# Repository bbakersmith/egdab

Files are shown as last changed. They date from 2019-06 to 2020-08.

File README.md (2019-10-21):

# Egdab

An orchid shaped conference badge built around an ATTiny1606, created for
DefCon 27. Features audio, temperature, and touch sensors, as well as numerous
buttons, dipswitches, and potentiometers for user input. Outputs in the form of
several RGB LEDs and a two digit seven segment display.

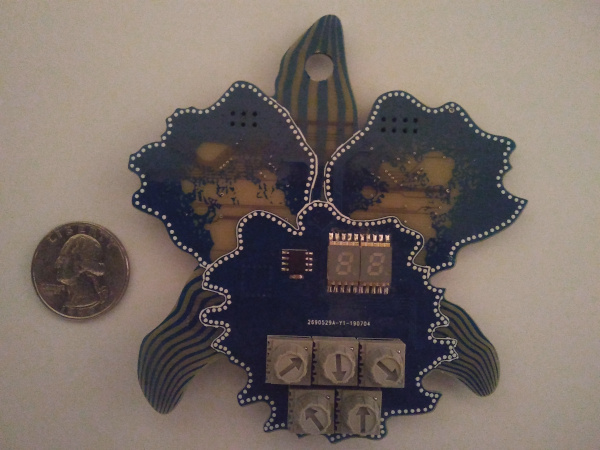
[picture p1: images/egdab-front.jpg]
Egdab front
\
Front

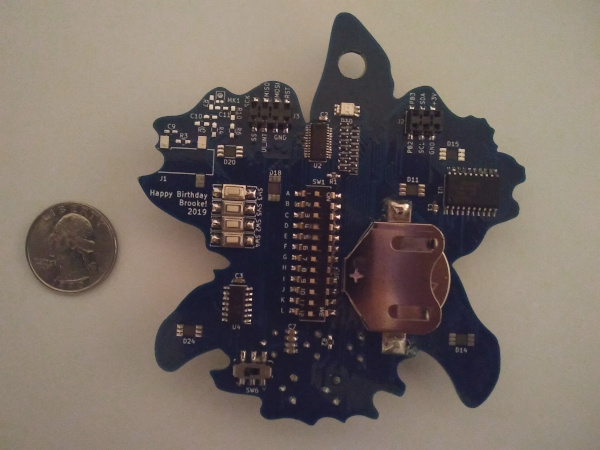
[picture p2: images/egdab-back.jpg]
Egdab back
\
Back

# License

Copyright Ben Baker-Smith 2019.

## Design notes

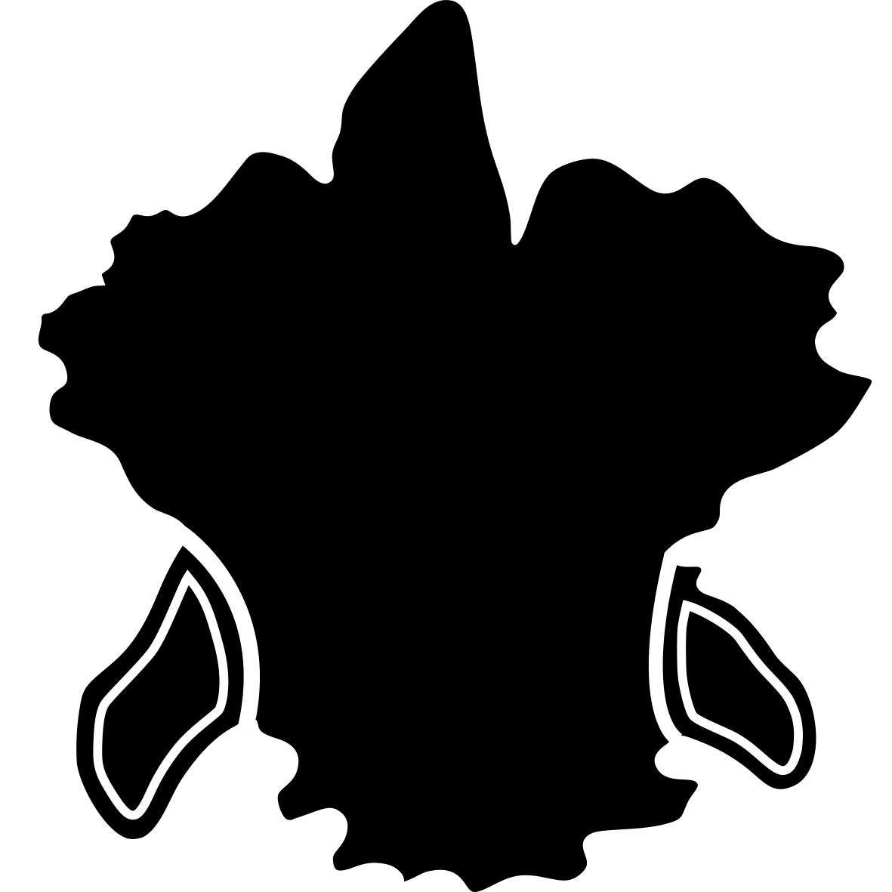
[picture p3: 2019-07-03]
graphic/exports/ground-1.png

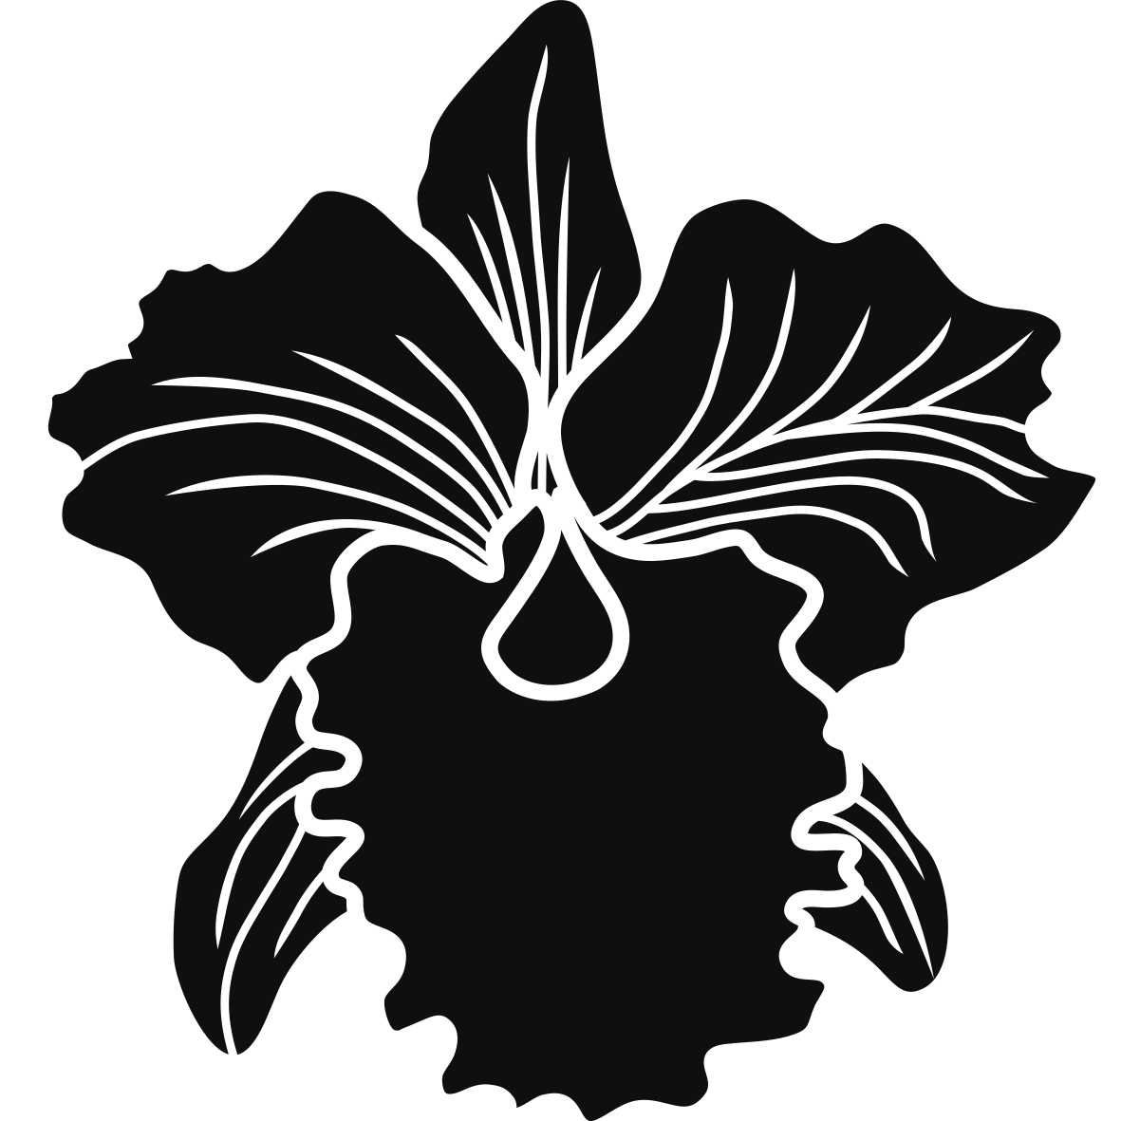
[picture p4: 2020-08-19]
kicad/graphics/orchid.png

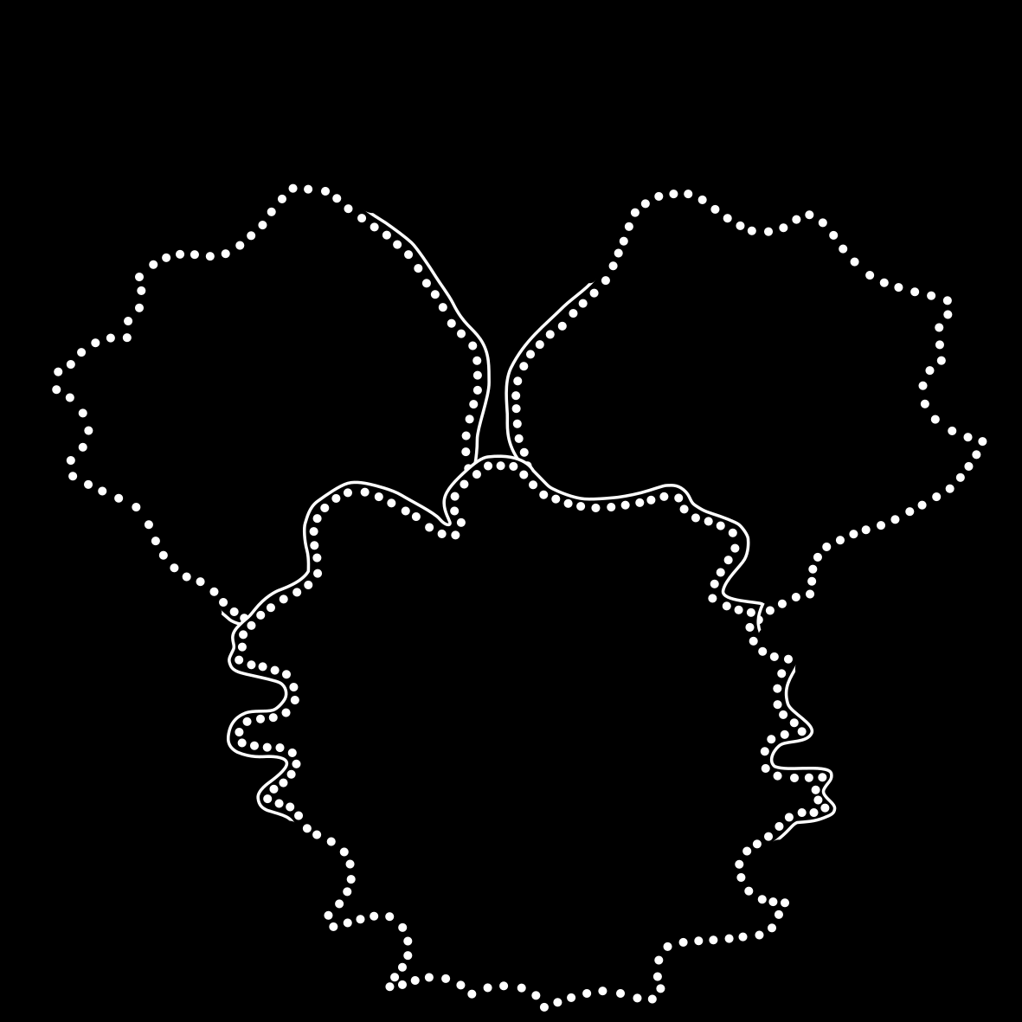
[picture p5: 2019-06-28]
graphic/exports/silkscreen-1.png

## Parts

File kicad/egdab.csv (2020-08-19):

Source: | /home/ben/dev/egdab/kicad/egdab.sch
Date: | Mon 17 Aug 2020 06:51:07 PM EDT
Tool: | Eeschema 5.1.5-1.fc30
Component Count: | 51
Ref | Value | Footprint | Datasheet | Manufacturer | Vendor
BT1 | CR2450VP | Battery_Holders:Keystone_3008_1x2450-CoinCell | ~
C1 | 22uF | Capacitors_SMD:C_0603_HandSoldering | ~
C2 | 22uF | Capacitors_SMD:C_0603_HandSoldering | ~
C3 | 22uF | Capacitors_SMD:C_0603_HandSoldering | ~
C4 | 22uF | Capacitors_SMD:C_0603_HandSoldering | ~
C5 | 22uF | Capacitors_SMD:C_0603_HandSoldering | ~
C6 | 22uF | Capacitors_SMD:C_0603_HandSoldering | ~
C9 | 10uF | Capacitors_SMD:C_0603_HandSoldering | ~
C10 | 10uF | Capacitors_SMD:C_0603_HandSoldering | ~
D1 | LED_RGB | BBS Components:LED_RGB_SMD_PLCC4_Reverse_XZMDKCBDDG45S | ~
D2 | LED_RGB | BBS Components:LED_RGB_SMD_PLCC4_Reverse_XZMDKCBDDG45S | ~
D3 | LED_RGB | BBS Components:LED_RGB_SMD_PLCC4_Reverse_XZMDKCBDDG45S | ~
D4 | LED_RGB | BBS Components:LED_RGB_SMD_PLCC4_Reverse_XZMDKCBDDG45S | ~
D5 | LED_RGB | BBS Components:LED_RGB_SMD_PLCC4_Reverse_XZMDKCBDDG45S | ~
D6 | LED_RGB | BBS Components:LED_RGB_SMD_PLCC4_Reverse_XZMDKCBDDG45S | ~
D7 | LED_RGB | BBS Components:LED_RGB_SMD_PLCC4_Reverse_XZMDKCBDDG45S | ~
D8 | LED_RGB | BBS Components:LED_RGB_SMD_PLCC4_Reverse_XZMDKCBDDG45S | ~
D9 | LED_RGB | BBS Components:LED_RGB_SMD_PLCC4_Reverse_XZMDKCBDDG45S | ~
D10 | LED_RGB | BBS Components:LED_RGB_SMD_PLCC4_Reverse_XZMDKCBDDG45S | ~
D11 | LED_RGB | BBS Components:LED_RGB_SMD_PLCC4_Reverse_XZMDKCBDDG45S | ~
D12 | LED_RGB | BBS Components:LED_RGB_SMD_PLCC4_Reverse_XZMDKCBDDG45S | ~
D13 | LED_RGB | BBS Components:LED_RGB_SMD_PLCC4_Reverse_XZMDKCBDDG45S | ~
D14 | LED_RGB | BBS Components:LED_RGB_SMD_PLCC4_Reverse_XZMDKCBDDG45S | ~
D15 | LED_RGB | BBS Components:LED_RGB_SMD_PLCC4_Reverse_XZMDKCBDDG45S | ~
D16 | LED_RGB | BBS Components:LED_RGB_SMD_PLCC4_Reverse_XZMDKCBDDG45S | ~
J2 | Conn_02x03_Counter_Clockwise | BBS Components:Header_SMD_vertical_passthrough_02x03 | ~
J3 | Conn_02x04_Counter_Clockwise | BBS Components:Header_SMD_vertical_passthrough_02x04 | ~
MK1 | Microphone | BBS Components:spv1840l45h-b | ~
R1 | 22K | Resistors_SMD:R_0603_HandSoldering | ~
R2 | 10K | Resistors_SMD:R_0603_HandSoldering | ~
R3 | 10K | Resistors_SMD:R_0603_HandSoldering | ~
R4 | 10K | Resistors_SMD:R_0603_HandSoldering | ~
R5 | 10K | Resistors_SMD:R_0603_HandSoldering | ~
R6 | 10K | Resistors_SMD:R_0603_HandSoldering | ~
R7 | R_PHOTO | LEDs:LED_D4.0mm | ~
R8 | 4K7 | Resistors_SMD:R_0603_HandSoldering | ~
R9 | 4K7 | Resistors_SMD:R_0603_HandSoldering | ~
R10 | 10K | Resistors_SMD:R_0603_HandSoldering | ~
R11 | 10K | Resistors_SMD:R_0603_HandSoldering | ~
R12 | 10K | Resistors_SMD:R_0603_HandSoldering | ~
R13 | 10K | Resistors_SMD:R_0603_HandSoldering | ~
RV1 | R_POT | Potentiometers:Potentiometer_Trimmer_Suntan_TSR-3386P_Horizontal | ~
RV2 | R_POT | Potentiometers:Potentiometer_Trimmer_Suntan_TSR-3386P_Horizontal | ~
RV3 | R_POT | Potentiometers:Potentiometer_Trimmer_Suntan_TSR-3386P_Horizontal | ~
RV4 | R_POT | Potentiometers:Potentiometer_Trimmer_Suntan_TSR-3386P_Horizontal | ~
SW1 | SW_DIP_x04 | Buttons_Switches_SMD:SW_DIP_x4_W8.61mm_Slide_LowProfile | ~
SW2 | SW_Push | BBS Components:SW_SPST_SMD_3_6 | ~
SW6 | SW_SPST | Digikey:Switch_Slide_JS202011SCQN | ~
U1 | ATtiny1606-S | Housings_SOIC:SOIC-20W_7.5x12.8mm_Pitch1.27mm | http://ww1.microchip.com/downloads/en/DeviceDoc/ATtiny806_1606_Data_Sheet_40002029A.pdf
U2 | AS1115-BSST | Housings_SSOP:SSOP-24_3.9x8.7mm_Pitch0.635mm | https://ams.com/documents/20143/36005/AS1115_DS000206_1-00.pdf/3d3e6d35-b184-1329-adf9-2d769eb2404f
U3 | LM35-D | Housings_SOIC:SOIC-8_3.9x4.9mm_Pitch1.27mm | http://www.ti.com/lit/ds/symlink/lm35.pdf

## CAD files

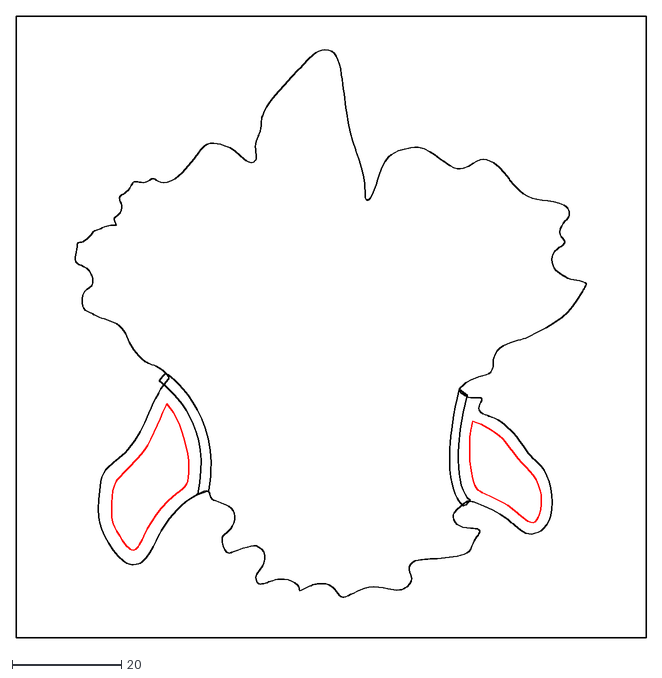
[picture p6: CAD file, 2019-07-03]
graphic/exports/ground-1.dxf
115.1 x 113.5

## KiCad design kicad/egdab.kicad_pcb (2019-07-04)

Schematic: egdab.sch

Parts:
BT1: CR2450VP; Keystone_3008_1x2450-CoinCell
C1, C2, C3, C4, C5, C6, C7, C8: 22uF; C_0603_HandSoldering
C9, C10, C11: 10uF; C_0603_HandSoldering
D1, D2, D3, D4, D5, D6, D7, D8, D9, D12, D13, D16, D17, D19, D21, D22: D; D_SOD-523
D10, D11, D14, D15, D18, D20, D24: LED_RGB; LED_RGB_SMD_PLCC4_Reverse_XZMDKCBDDG45S
D23: 7SegmentLED_ACDA02
J1: Audio-Jack-2_Switch; sj2-35852b-smt
J2: Conn_02x03_Counter_Clockwise; Header_SMD_vertical_passthrough_02x03
J3: Conn_02x04_Counter_Clockwise; Header_SMD_vertical_passthrough_02x04
MK1: Microphone; spv1840l45h-b
R1: 22K; R_0603_HandSoldering
R2, R3, R4, R5, R6, R7, R10: 10K; R_0603_HandSoldering
RV1, RV2, RV3, RV4, RV5: R_POT; Potentiometer_Trimmer_Suntan_TSR-3386P_Horizontal
SW1: SW_DIP_x12; SW_DIP_x12_W8.61mm_Slide_LowProfile
SW2, SW3, SW4, SW5: SW_Push; SW_SPST_SMD_3_6
SW6: SW_SPST; Switch_Slide_JS202011SCQN
U1: ATtiny1606-S; SOIC-20W_7.5x12.8mm_Pitch1.27mm
U2: AS1115-BSST; SSOP-24_3.9x8.7mm_Pitch0.635mm
U3: LM35-D; SOIC-8_3.9x4.9mm_Pitch1.27mm
U4: CAP1296; SOIC-14_3.9x8.7mm_Pitch1.27mm

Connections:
/ALL_SEG: D9.1 (K), D10.2, D11.2, D12.1 (K), D13.1 (K), D14.2, D15.2, D16.1 (K), D17.1 (K), D18.2, D19.1 (K), D20.2, D21.1 (K), D22.1 (K), D24.2
/AS1115_ISET: R1.2, U2.13 (ISET)
/AUDIO: C9.2, R6.1, U1.5 (PA7)
/BAT+: BT1.1 (+), SW6.2
/DIG0: D10.1, D14.1, D24.1, U2.2 (DIG0)
/DIG1: D10.4, D14.4, D24.4, U2.3 (DIG1)
/DIG2: D10.3, D14.3, D24.3, U2.4 (DIG2)
/DIG3: D23.8, D23.13, U2.5 (DIG3)
/DIG4: D23.3, D23.18, U2.7 (DIG4)
/DIG5: D11.1, D15.1, D18.1, D20.1, U2.8 (DIG5)
/DIG6: D11.4, D15.4, D18.4, D20.4, U2.9 (DIG6)
/DIG7: D11.3, D15.3, D18.3, D20.3, U2.10 (DIG7)
/KEYA: SW1.1, SW1.2, SW1.3, SW1.4, SW1.5, SW1.6, SW1.7, SW1.8, U2.11 (KEYA)
/KEYB: SW1.9, SW1.10, SW1.11, SW1.12, SW2.1, SW3.1, SW4.1, SW5.1, U2.12 (KEYB)
/MIC: C11.2, R10.1, U1.6 (PB5)
/POT1: RV1.2, U1.17 (PA1)
/POT2: RV2.2, U1.18 (PA2)
/POT3: RV3.2, U1.19 (PA3)
/POT4: RV4.2, U1.2 (PA4)
/POT5: RV5.2, U1.3 (PA5)
/SEGA: D8.2 (A), D22.2 (A), D23.12, D23.17, U2.15 (SEGA)
/SEGB: D7.2 (A), D21.2 (A), D23.11, D23.16, U2.17 (SEGB)
/SEGC: D6.2 (A), D19.2 (A), D23.4, D23.9, U2.20 (SEGC)
/SEGD: D5.2 (A), D17.2 (A), D23.2, D23.7, U2.23 (SEGD)
/SEGDP: D1.2 (A), D9.2 (A), D23.5, D23.10, U2.22 (SEGDP)
/SEGE: D4.2 (A), D16.2 (A), D23.1, D23.6, U2.21 (SEGE)
/SEGF: D3.2 (A), D13.2 (A), D23.14, D23.19, U2.16 (SEGF)
/SEGG: D2.2 (A), D12.2 (A), D23.15, D23.20, U2.18 (SEGG)
/TEMP: U1.4 (PA6), U3.1 (Vout)
GND: BT1.2 (-), C1.2, C2.2, C3.2, C4.2, C5.2, C6.2, C7.2, C8.2, C10.1, J1.2, J2.1, J3.1, J3.2, MK1.1 (-), R3.2, R5.2, R7.2, RV1.3, RV2.3, RV3.3, RV4.3, RV5.3, U1.20 (GND), U2.6 (GND), U3.4 (GND), U4.8, U4.9, U4.10
I2C_SCL: J2.2, U1.11 (PB0), U2.14 (SCL), U4.5
I2C_SDA: J2.5, U1.10 (PB1), U2.1 (SDA), U4.4
unnamed: C9.1, J1.1, R3.1
unnamed: C10.2, R4.2, R5.1, R6.2, R10.2
unnamed: C11.1, MK1.2 (+), R7.1
unnamed: D1.1 (K), SW1.16, SW1.24
unnamed: D2.1 (K), SW1.15, SW1.23
unnamed: D3.1 (K), SW1.14, SW1.22
unnamed: D4.1 (K), SW1.13, SW1.21
unnamed: D5.1 (K), SW1.20, SW2.2
unnamed: D6.1 (K), SW1.19, SW3.2
unnamed: D7.1 (K), SW1.18, SW4.2
unnamed: D8.1 (K), SW1.17, SW5.2
unnamed: R2.1, RV1.1, RV2.1, RV3.1, RV4.1, RV5.1
PB2: J2.3, U1.9 (PB2)
PB3: J2.4, U1.8 (PB3)
RESET: J3.8, U1.16 (~RESET~/PA0)
SPI_MISO: J3.6, U1.14 (PC2)
SPI_MOSI: J3.7, U1.13 (PC1)
SPI_SCK: J3.5, U1.15 (PC3)
SPI_SS: J3.4, U1.12 (PC0)
TOUCH1: U4.2
TOUCH2: U4.13
TOUCH_GUARD: U4.11
TOUCH_PROX: U4.12
UI_INTERRUPT: J3.3, U1.7 (PB4), U2.24 (IRQ), U4.3

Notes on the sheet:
TODO share voltage divider and capacitor between audio sources

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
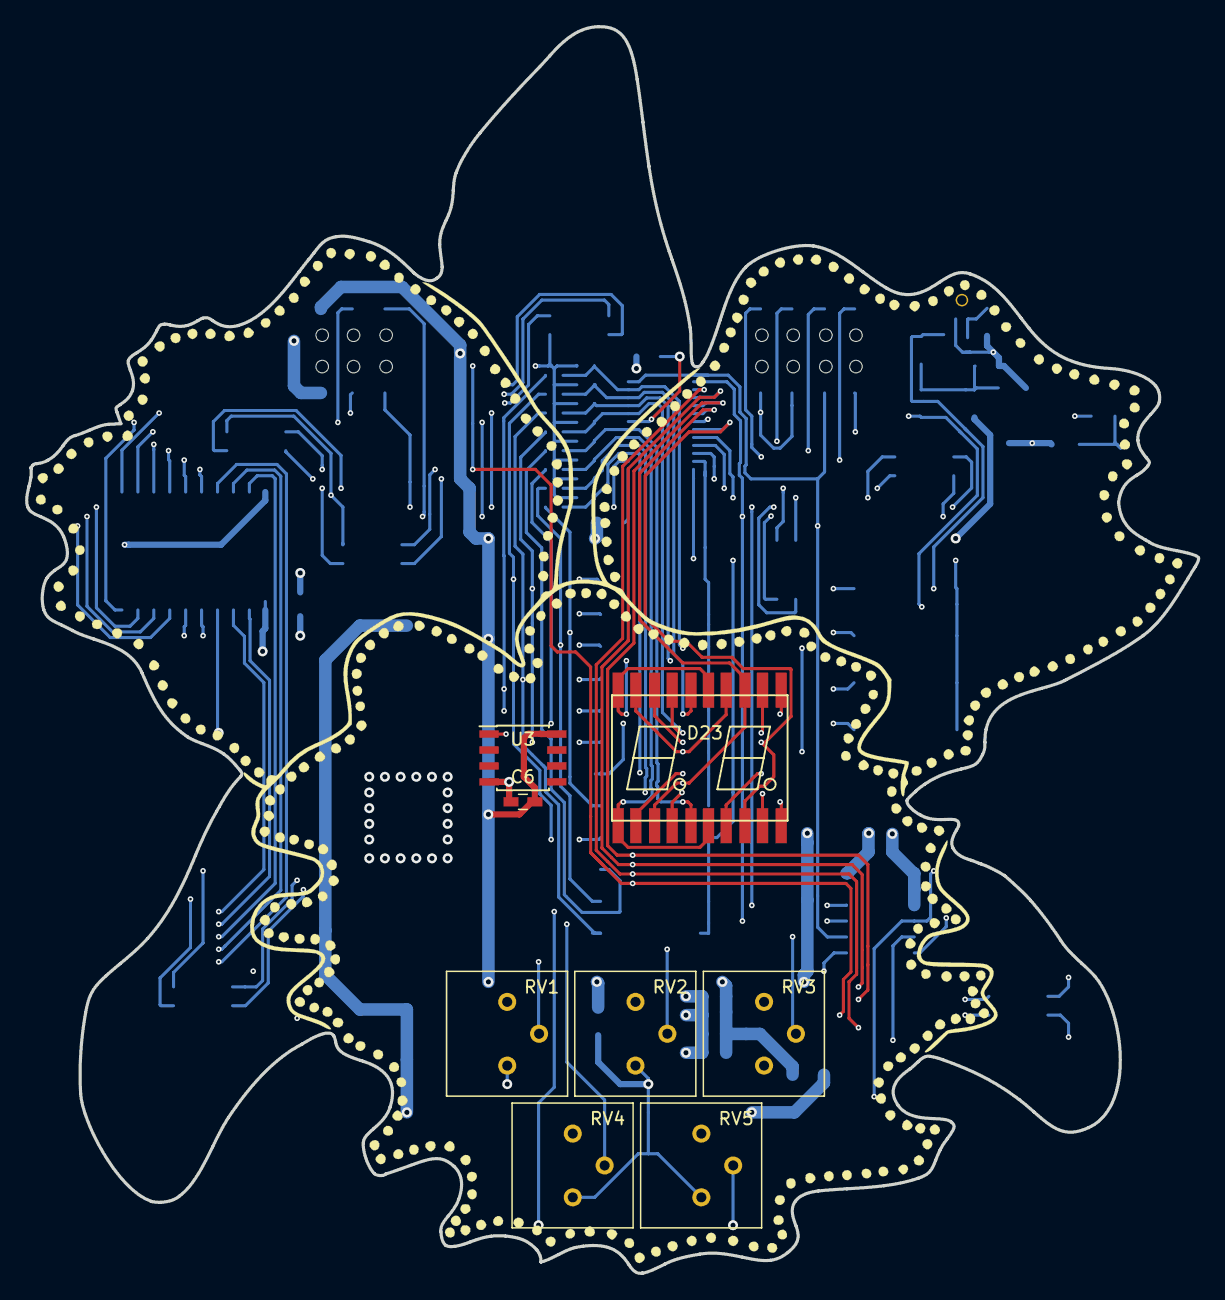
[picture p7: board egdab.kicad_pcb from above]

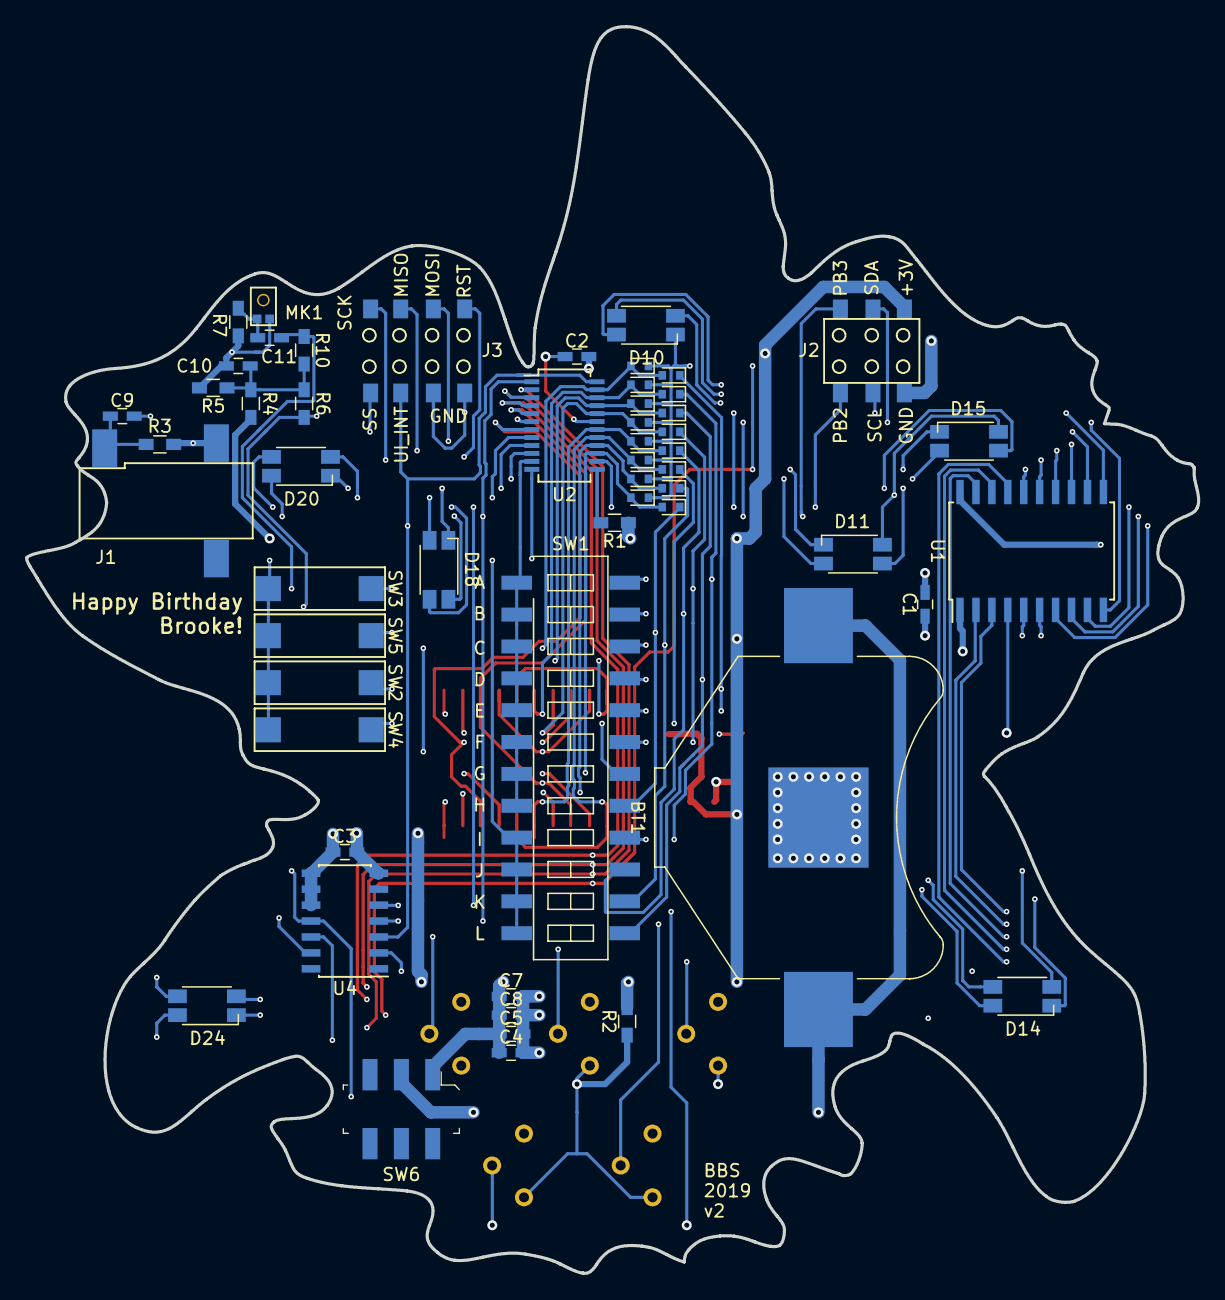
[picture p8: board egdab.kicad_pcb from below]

Board: 4 copper layers, 93.4 x 99.4 mm, 63 parts (55 on the bottom side), 53 nets.

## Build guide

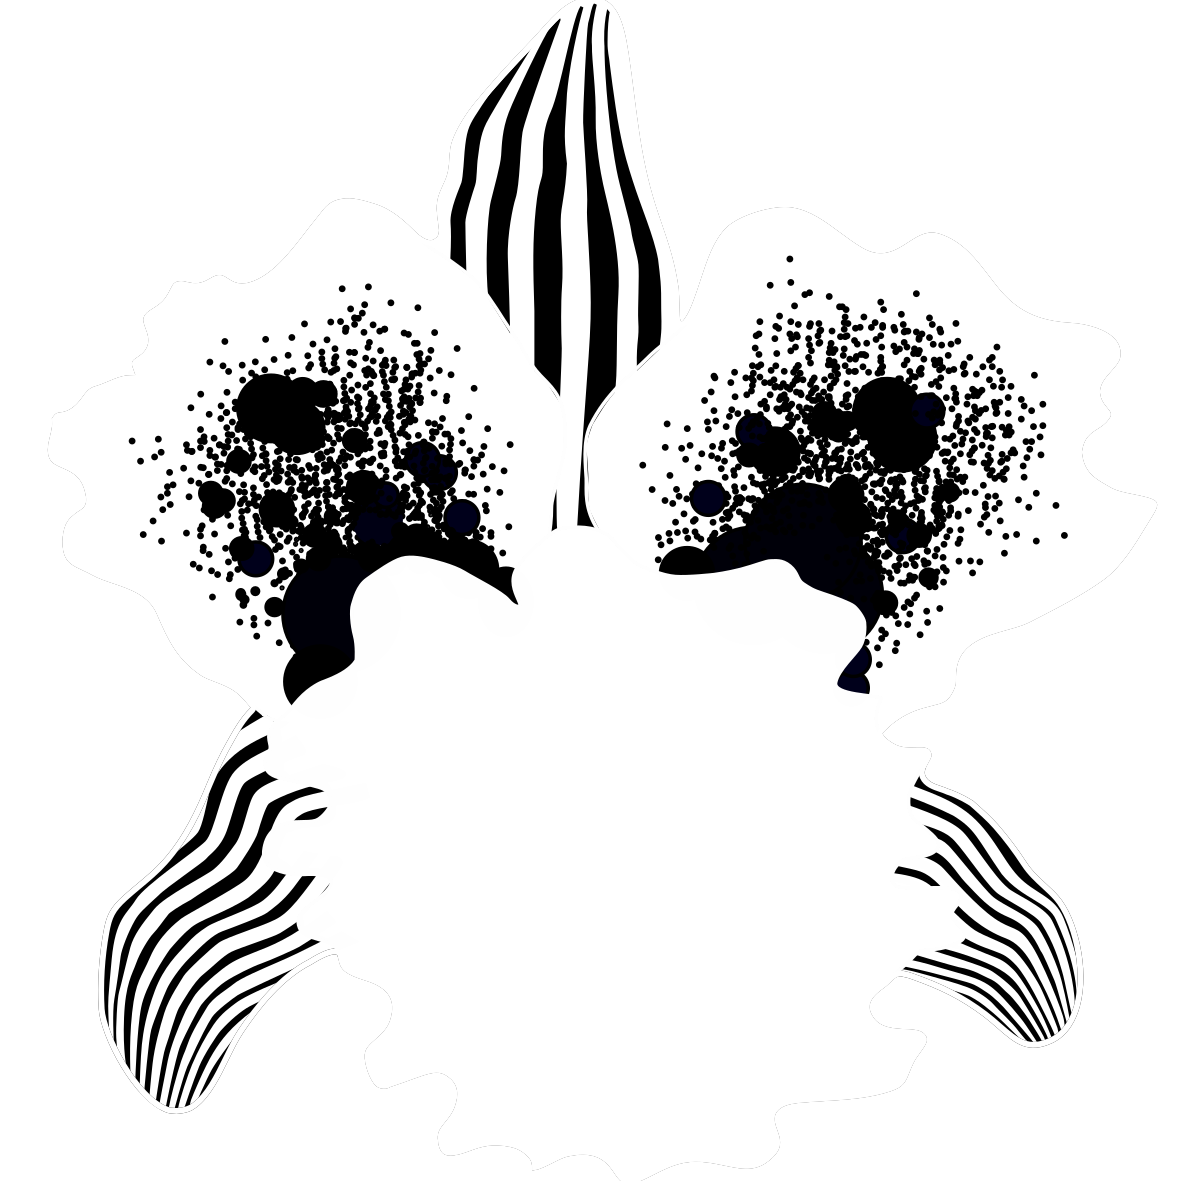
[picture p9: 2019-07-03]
graphic/exports/soldermask-2.png

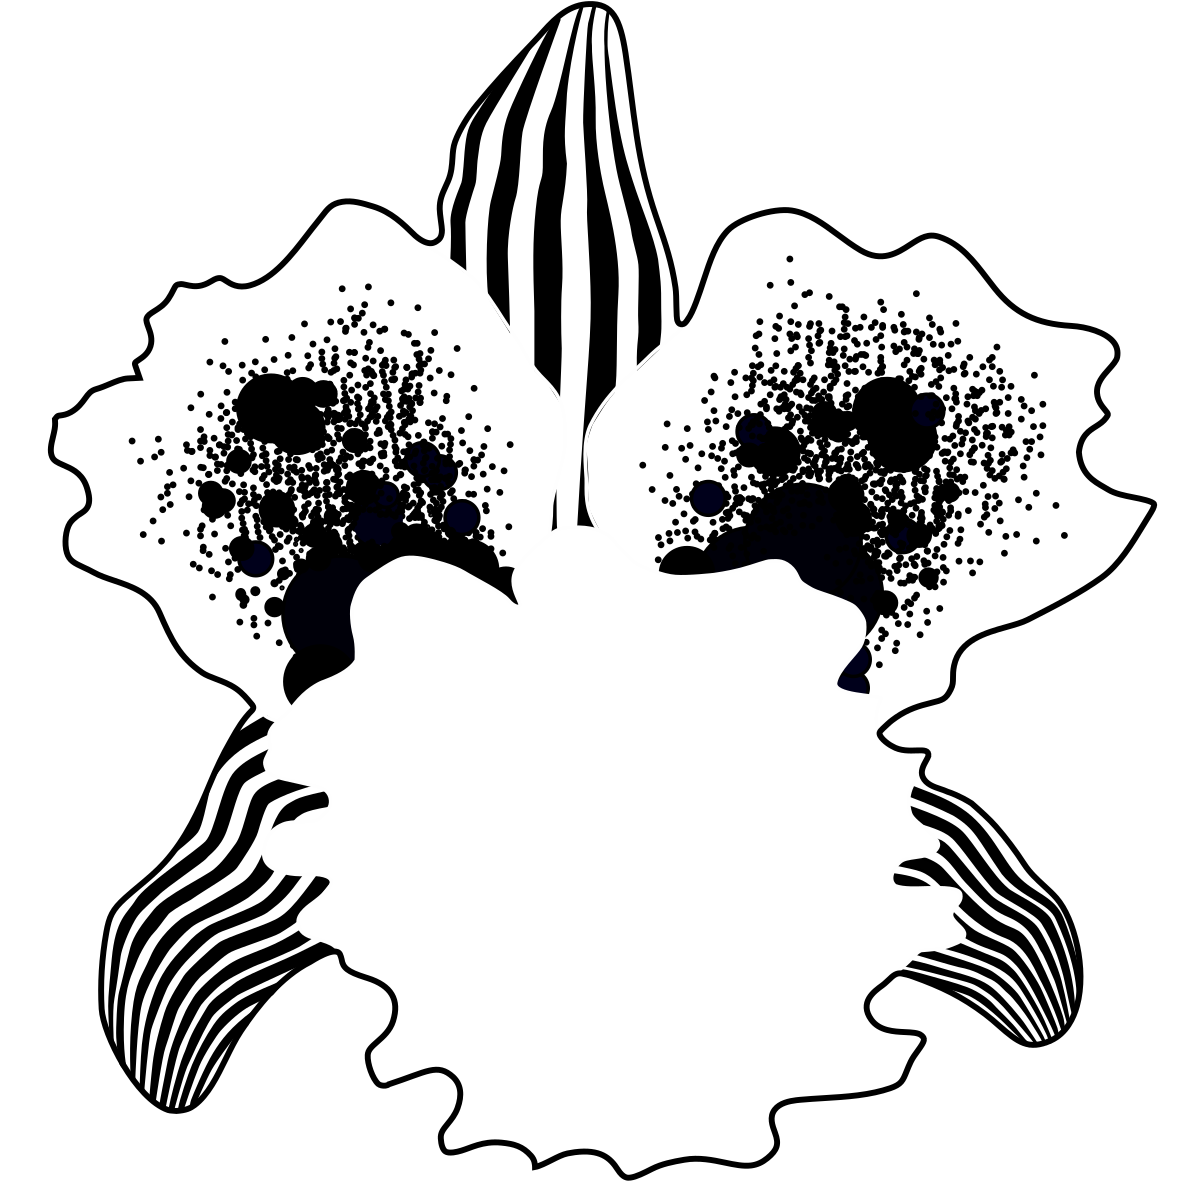
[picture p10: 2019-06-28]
graphic/exports/soldermask-1.png

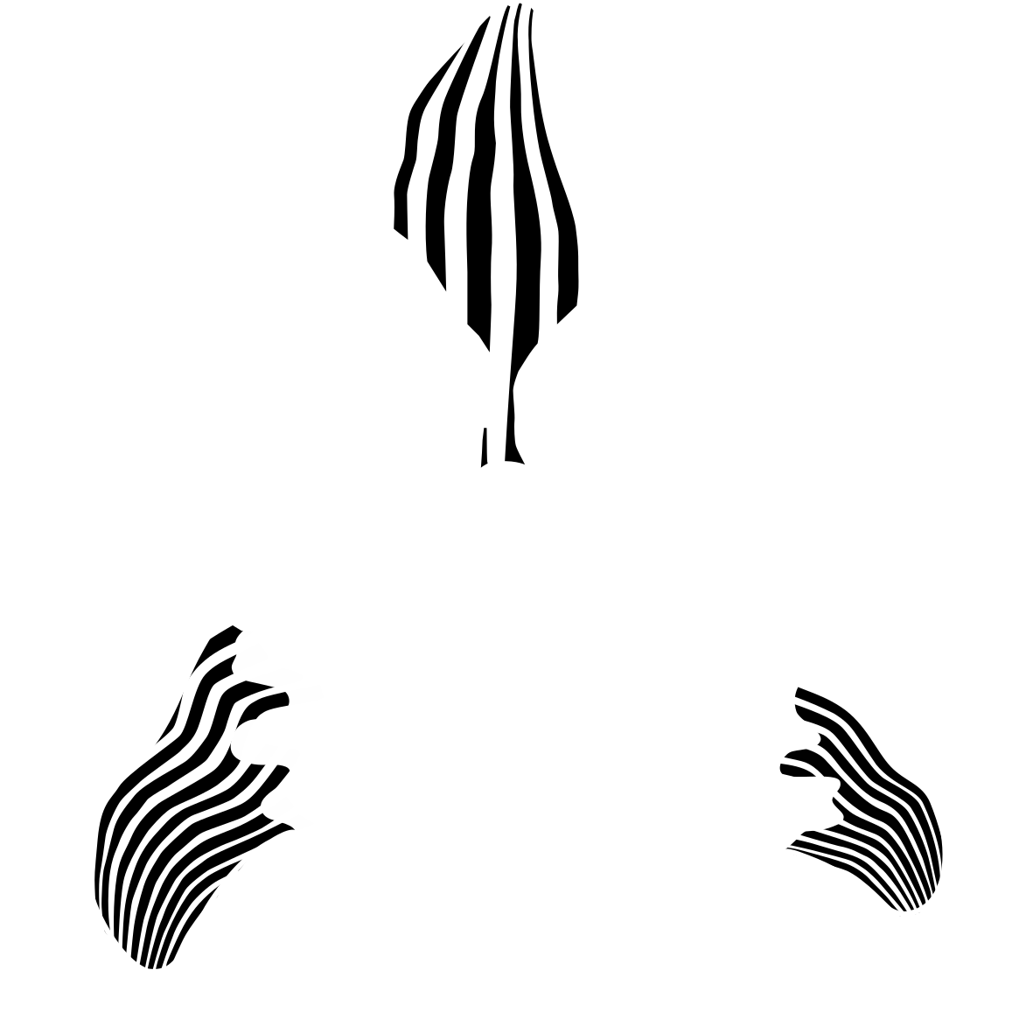
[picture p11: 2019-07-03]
graphic/exports/soldermask-2a.png

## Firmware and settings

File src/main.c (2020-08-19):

/*
 * egdab.c
 *
 * Created: 7/22/2019 8:23:05 PM
 * Author : ben
 */

#include <avr/interrupt.h>
#include <avr/io.h>
#include <stdbool.h>
#include <stdint.h>

#define F_CPU 3333333UL
#include <util/delay.h>

#include "controller.h"
#include "digit.h"
#include "twi.h"

#define PIN2 2
#define PIN3 3
#define PIN4 4
#define PIN5 5

#define MCTRLA_ENABLE 0
#define MCTRLA_WIEN 6
#define MCTRLA_RIEN 7

#define MSTATUS_WIF 6

#define AS1115_ADDR 0
#define CAP1296_ADDR 0x50

Twi twi;

void twi_addr_fn(uint8_t addr) {
  TWI0.MADDR = addr;
}

void twi_write_data_fn(uint8_t data) {
  /* while(!(TWI0.MSTATUS & (1 << 6))) {} */
  TWI0.MDATA = data;
}

void twi_stop_fn(void) {
	/* while(!(TWI0.MSTATUS & (1 << 6))) {} */
	TWI0.MCTRLB |= 3;
}

void egdab_twi_write(uint8_t address, uint8_t data[], uint8_t len) {
// TODO
// - load the data in buffer
// - write the address to MADDR
// - wait til write interrupt
// - write data to MDATA
// - wait til write interrupt
// - write data to MDATA
// - when buffer empty, write STOP cmd to MCTRLB

	TWI0.MADDR = address;
	for(uint8_t i = 0; i < len; i++) {
		// Wait until CLKHOLD cleared
		while(!(TWI0.MSTATUS & (1 << 6))) {}
		TWI0.MDATA = data[i];
	}
	while(!(TWI0.MSTATUS & (1 << 6))) {}
	TWI0.MCTRLB |= 3; // STOP command
}

uint8_t egdab_knob_position(uint8_t knob) {
	ADC0.MUXPOS = knob;
	ADC0.COMMAND = 1;
	while(ADC0.COMMAND) {}
	return (uint8_t) ADC0.RES;
}

void as1115_write(uint8_t reg, uint8_t data) {
  PORTB.OUTTGL = (1 << PIN2);
  uint8_t buffer[2];
  buffer[0] = reg;
  buffer[1] = data;
  egdab_twi_write(AS1115_ADDR, buffer, 2);
  /* twi_write(&twi, AS1115_ADDR, buffer, 2); */
}

void write_color1(uint8_t hue) {
  Color color;
  color.hue = hue;
  color_hue_to_rgb(&color);

  uint8_t red = controller_apply_range(0, 15, color.red);
  uint8_t green = controller_apply_range(0, 15, color.green);
  uint8_t blue = controller_apply_range(0, 15, color.blue);

  as1115_write(0x10, (red << 4));
  as1115_write(0x11, (blue << 4) | green);

  if(red == 0) {
    as1115_write(0x02, 0x00);
  } else {
    as1115_write(0x02, 0xFF);
  }

  if(green == 0) {
    as1115_write(0x03, 0x00);
  } else {
    as1115_write(0x03, 0xFF);
  }

  if(blue == 0) {
    as1115_write(0x04, 0x00);
  } else {
    as1115_write(0x04, 0xFF);
  }
}

void write_color2(uint8_t hue) {
  Color color;
  color.hue = hue;
  color_hue_to_rgb(&color);

  uint8_t red = controller_apply_range(0, 15, color.red);
  uint8_t green = controller_apply_range(0, 15, color.green);
  uint8_t blue = controller_apply_range(0, 15, color.blue);

  as1115_write(0x12, (green << 4) | red);
  as1115_write(0x13, (blue << 4));

  if(red == 0) {
    as1115_write(0x05, 0x00);
  } else {
    as1115_write(0x05, 0xFF);
  }

  if(green == 0) {
    as1115_write(0x06, 0x00);
  } else {
    as1115_write(0x06, 0xFF);
  }

  if(blue == 0) {
    as1115_write(0x07, 0x00);
  } else {
    as1115_write(0x07, 0xFF);
  }
}

int main(void) {
  // TODO FIXME still running with default 1/6 prescaler (see F_CPU above)
  // System clock configuration, disable prescaler, 1606 defaults to 20Mhz
  CLKCTRL.MCLKCTRLB = 0;

	// TWI setup
	TWI0.MBAUD = 50;
	TWI0.MSTATUS = 1;
	TWI0.MCTRLA = (1 << MCTRLA_RIEN) | (1 << MCTRLA_WIEN) | (1 << MCTRLA_ENABLE);

  twi = twi_new(
    &twi_addr_fn,
    &twi_write_data_fn,
    &twi_stop_fn
  );

	// Input pin setup
	PORTA.DIRCLR |= (1 << PIN4) | (1 << PIN5);
	PORTA.PIN4CTRL = 4; // disable input buffer
	PORTA.PIN5CTRL = 4; // disable input buffer

	// ADC setup
	ADC0.CTRLA = (1 << 2) | 1; // enable 8bit adc
	ADC0.MUXPOS = 4; // select pin 4

	// Output pin setup
	PORTB.DIRSET |= (1 << PIN2) | (1 << PIN3);
	PORTB.OUTCLR |= (1 << PIN2) | (1 << PIN3);

  sei();

	// shutdown mode, normal with defaults
  as1115_write(0x0C, 0x01);

  // global intensity
  as1115_write(0x10, 0x00);
  as1115_write(0x11, 0x00);
  as1115_write(0x12, 0x00);
  as1115_write(0x13, 0x00);
  as1115_write(0x0A, 0x0F);

	// decode mode
  as1115_write(0x09, 0x00);

	// scan limit
  as1115_write(0x0B, 0xFF);

  for(uint8_t i = 1; i < 9; i++) {
    as1115_write(i, 0x00);
    /* as1115_write(i, 0xFF); */
  }

  // top red x02
  // top green x03
  // top blue x04
  //
  // side red x05
  // side green x06
  // side blue x07

  /* as1115_write(0x07, 0xFF); */

  /* write_color1(255); */

  as1115_write(0x01, DIGIT_0);
  _delay_ms(100);
  as1115_write(0x01, DIGIT_1);
  _delay_ms(100);
  as1115_write(0x01, DIGIT_2);
  _delay_ms(100);
  as1115_write(0x01, DIGIT_3);
  _delay_ms(100);
  as1115_write(0x01, DIGIT_4);
  _delay_ms(100);
  as1115_write(0x01, DIGIT_5);
  _delay_ms(100);
  as1115_write(0x01, DIGIT_6);
  _delay_ms(100);
  as1115_write(0x01, DIGIT_7);
  _delay_ms(100);
  as1115_write(0x01, DIGIT_8);
  _delay_ms(100);
  as1115_write(0x01, DIGIT_9);
  _delay_ms(100);
  as1115_write(0x01, 0);

	while(true) {
    for(uint16_t i = 0; i < 256; i++) {
      write_color1(i);
      write_color2((uint8_t) i / 2);
      _delay_ms(50);
    }
  }

	return 0;
}

ISR(TWI0_TWIM_vect) {
  // TODO handle read interrupt?
  twi_handle_write_interrupt(&twi);
  PORTB.OUTTGL = (1 << PIN3);
}

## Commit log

2019-06-17 Schematic WIP
    [egdab.sch]
2019-06-18 Global labels
    [egdab.sch]
2019-06-18 AS1115 takeover, needs diodes for keyscan
    [egdab.sch]
2019-06-18 ATtiny1606 instead of Atmega328p
    [egdab.sch]
2019-06-20 First draft of schematic
    [egdab.sch]
2019-06-21 PCB WIP
    [egdab.kicad_pcb, egdab.sch]
2019-06-28 Big things
    [egdab.kicad_pcb, egdab.sch]
2019-06-30 PCB layout progress
    [egdab.kicad_pcb, egdab.sch]
2019-07-03 Draft 1 may be complete
    [egdab.kicad_pcb, egdab.sch, ground-1.dxf]
2019-07-04 v2 PCB in progress
    - board version added to silk
    - use actual reverse mount RGB LEDs
    - invert lower petal soldermask
    [egdab.kicad_pcb, egdab.sch]
2019-08-16 Map analog inputs to LED hue and value
2019-08-17 Preparing to switch to twi module
2019-08-19 Move LED structs and fns into controller
2019-08-20 LED color control IRL
2020-08-19 new board RGB LED controll and 7-seg digits
    [egdab.csv, egdab.sch]
